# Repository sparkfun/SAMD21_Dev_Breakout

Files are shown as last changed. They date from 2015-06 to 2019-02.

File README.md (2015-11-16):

SparkFun SAMD21 Dev Breakout
========================================

SparkFun SAMD21 Dev Breakout

[*SparkFun SAMD21 Dev Breakout (DEV-13672)*](https://www.sparkfun.com/products/13672)

The SAMD21 Dev Breakout is an Arduino-sized breakout for the Atmel [ATSAMD21G18](http://www.atmel.com/devices/ATSAMD21G18A.aspx), a 32-bit ARM Cortex-M0+ processor with 256KB flash, 32KB SRAM, and an operating speed of up to 48MHz. The SAMD21 is compatible with the Arduino IDE, and libraries for the Arduino Zero.

Repository Contents
-------------------

* **/Documentation** - Data sheets, additional product information
* **/Firmware** - SAM_BA SAMD21 Bootloader
* **/Hardware** - Eagle design files (.brd, .sch)
* **/Production** - Production panel files (.brd)

Documentation
--------------
* **[Hookup Guide](https://learn.sparkfun.com/tutorials/samd21-Devdev-breakout-hookup-guide/resources--going-further)** - Basic hookup guide for the SAMD21 Dev Breakout.

Product Versions
----------------
* [DEV-13672](https://www.sparkfun.com/products/13672) - Initial product release - v10.
* [DEV-13672](https://www.sparkfun.com/products/13664) - The SparkFun SAMD21 _Mini_ Breakout -- a similar, Arduino-shaped version of this board.

Version History
---------------
* [v1.0](https://github.com/sparkfun/SAMD21_Dev_Breakout/tree/v10) - Initial release 

License Information
-------------------

This product is _**open source**_! 

Please review the LICENSE.md file for license information. 

If you have any questions or concerns on licensing, please contact techsupport@sparkfun.com.

Distributed as-is; no warranty is given.

- Your friends at SparkFun.

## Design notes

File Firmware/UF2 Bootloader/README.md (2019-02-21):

UF2 Bootloader for the SAMD21 DEV Breakout
==========================================
**Current Version**: UF2 Bootloader v3.2.2-1-gdec2fb7-dirty SFHWRO
**Updated**: 2/21/2019

What is UF2? It's probably best to read the documents [HERE](https://makecode.com/blog/one-chip-to-flash-them-all). The TLDR however, is that it's a bootloader that turns your micro-controller 
into a flash drive. The example bootloader provided here was created 2/21/2019
and further support is not guaranteed. However you can learn a bit about _how_
to build your own bootloader at Microsoft's [repo](https://github.com/Microsoft/uf2).
The hardest part will be ensuring that you have all the necessary build dependencies.

To update your SAMD21 DEV with the bootloader is simple. If you already have a
bootloader on it, i.e. you can see it populate in Arduino and/or Device
Manager, then all you have to do is open the "Update-Bootloader.ino" sketch and
upload it. Afterwards, you should see the SAMD21 pop up as a **SPARKFUN** drive. 
I have also included an "update" binary file for those that want to use some
GUI or command line interface instead, as well as _just_ the bootloader for
those that don't already have a bootloader installed on their micro-controller.

Circuit Python 
------------------
**Current Version**: 4.0.0-beta.1-46-g3d0757102   
**Updated**: 2/21/2019

Circuit Python is Adafruit's version of Micro Python. You can read general
information about it [HERE](https://learn.adafruit.com/welcome-to-circuitpython).
They also have some documentation on how to build a version of Circuit Python
on their website [here](https://learn.adafruit.com/building-circuitpython/build-circuitpython). 
I have included a build of it under the Circuit Python folder. Assuming that
you have uploaded the UF2 bootloader above, than all you need to do is drag and
drop the UF2 file in the Circuit Python folder into your **SPARKFUN** drive and 
you're good to go! The Sparkfun drive will momentarily disappear and a **CIRCUITPY** 
drive will take its place.

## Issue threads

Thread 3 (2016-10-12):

Unable to flash bootloader from Arduino IDE

dlabun, 2016-10-12:
With v1.2.1 of the SAMD21 core you cannot flash the bootloader from the Arduino IDE. The IDE is looking for the BIN file with the name "samd21_sam_ba.bin" when the file is actually named "samd21_sam_ba_sparkfun.bin"

ToniCorinne, 2017-02-07:
@jimblom can you see if this is still an issue? Thanks!

jimblom, 2017-02-08:
Shoot, looks like I forgot to close this issue out earlier.

"Burn bootloader" for SAMD21 Dev and Mini boards was fixed in the SparkFun SAMD core version 1.3.0. Verified that it works on the current version - 1.3.2.

Closed 2017-02-08.

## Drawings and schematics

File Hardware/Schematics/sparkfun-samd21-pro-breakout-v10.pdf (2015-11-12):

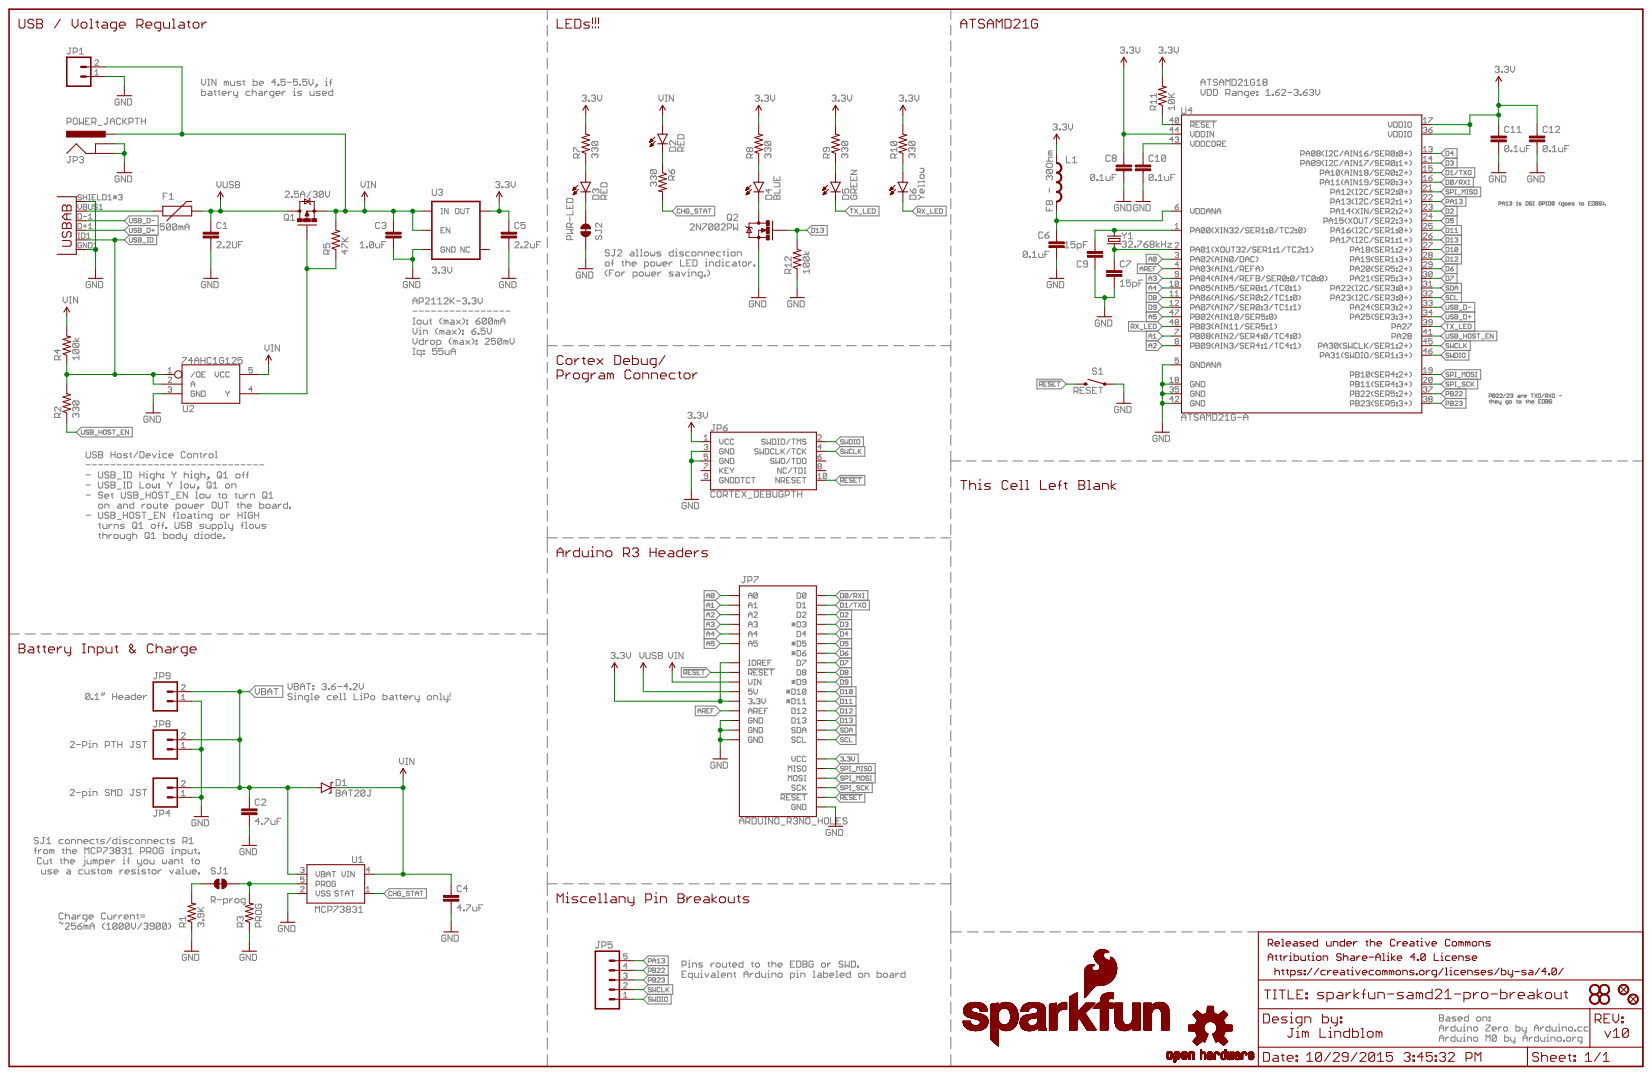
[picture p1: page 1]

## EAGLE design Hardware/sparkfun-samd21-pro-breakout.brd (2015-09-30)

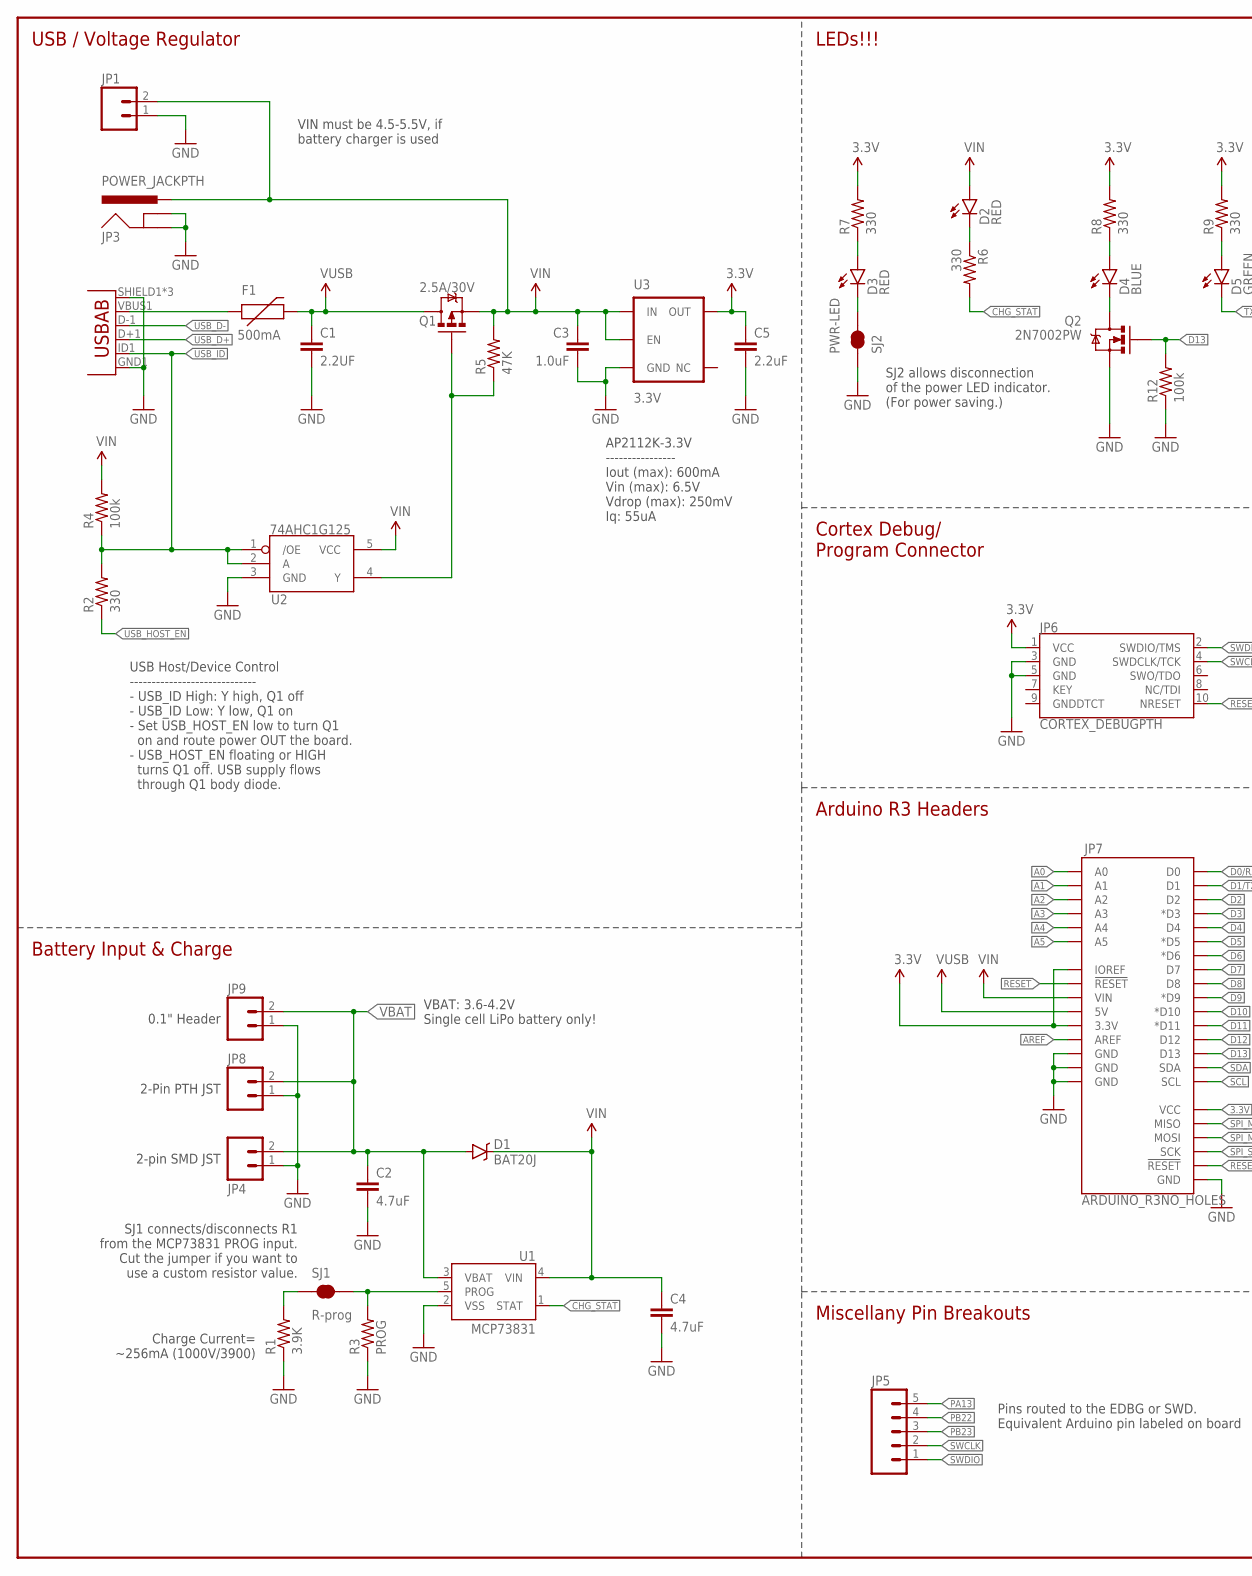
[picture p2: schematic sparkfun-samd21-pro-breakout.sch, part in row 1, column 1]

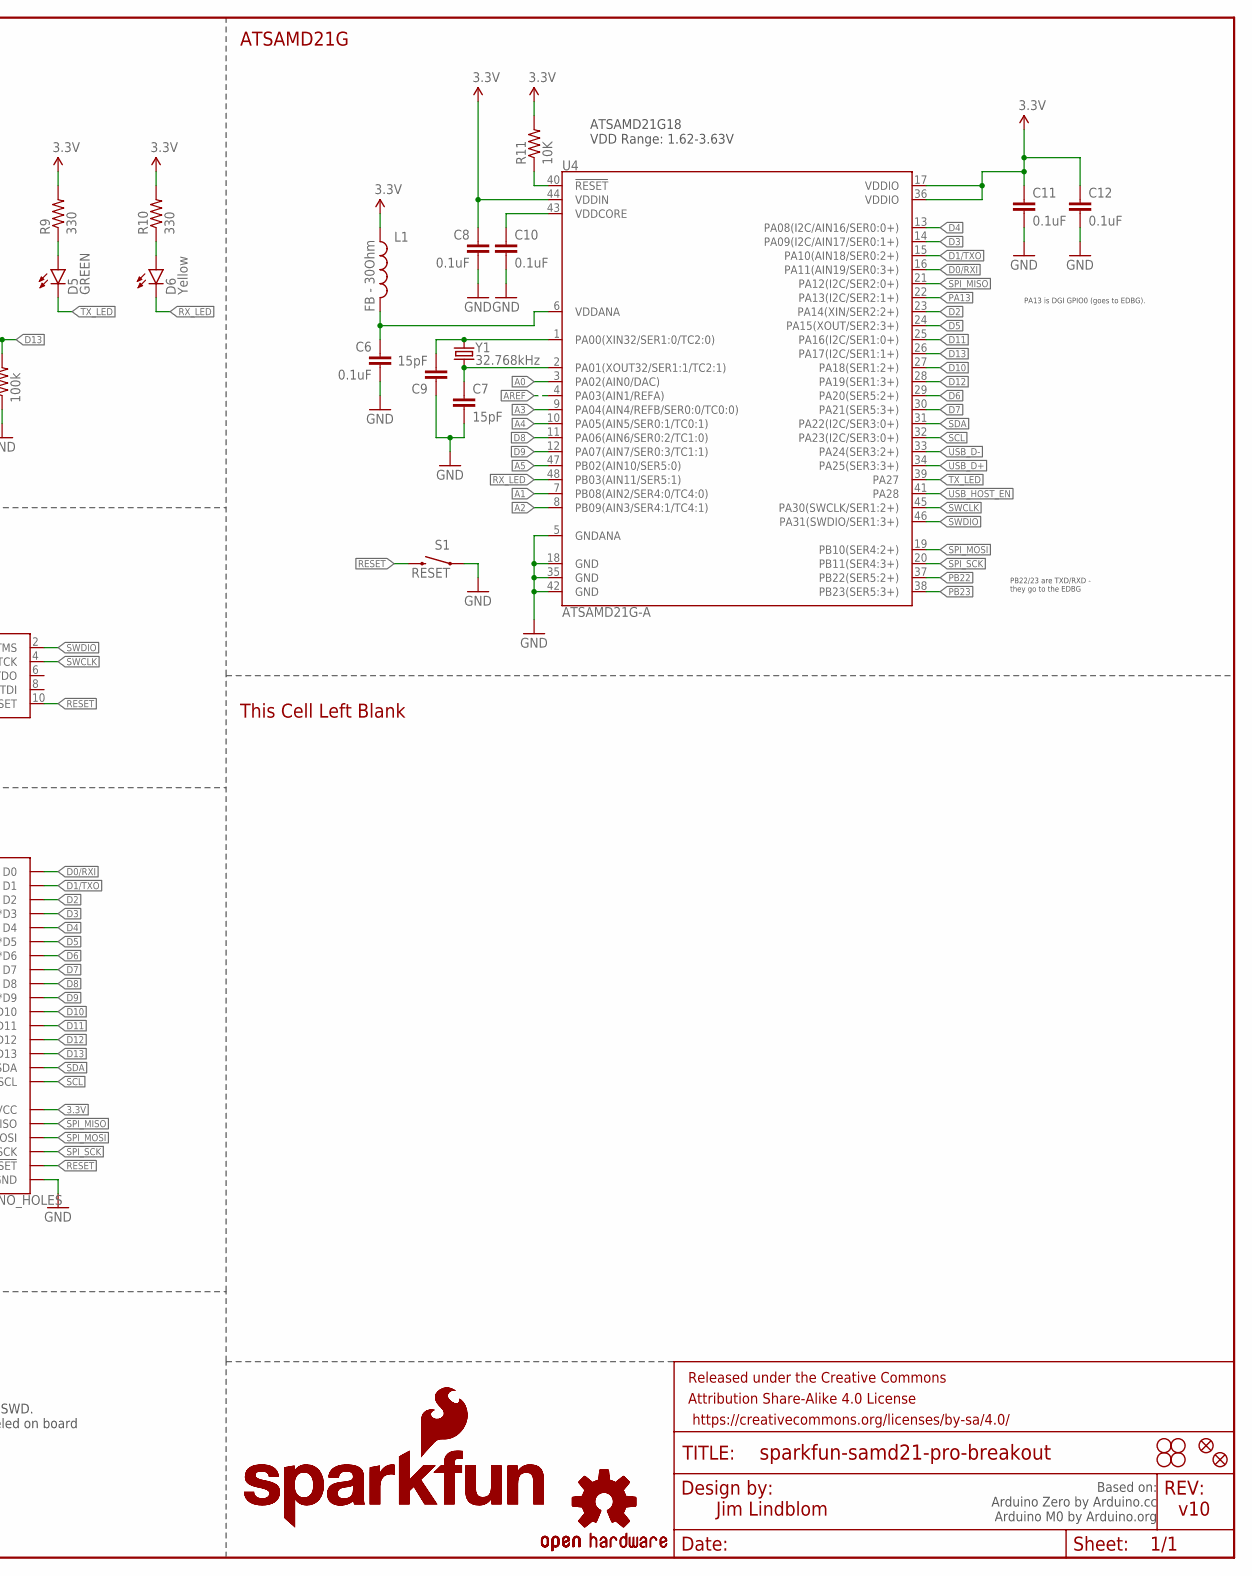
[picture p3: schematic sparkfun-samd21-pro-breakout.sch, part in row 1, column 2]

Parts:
C1: 2.2UF; 1206
C2, C4: 4.7uF; 0603-CAP
C3: 1.0uF; 0805-CAP
C5: 2.2uF; 0603-CAP
C6, C8, C10, C11, C12: 0.1uF; 0603-CAP
C7, C9: 15pF; 0603-CAP
D1: BAT20J; SOD-323
D2, D3: RED; LED-0603
D4: BLUE; LED-0603
D5: GREEN; LED-0603
D6: Yellow; LED-0603
F1: 500mA; PTC-1206
FID1, FID2: FIDUCIAL1X2; FIDUCIAL-1X2
FRAME1: FRAME-LEDGER; CREATIVE_COMMONS
JP1: M02PTH; 1X02
JP2: USB-ABCONN-11794; USB-AB-MICRO-SMD_V03
JP3: POWER_JACKPTH; POWER_JACK_PTH
JP4: M02-JST-2MM-SMT; JST-2-SMD
JP5: M05NO_SILK; 1X05_NO_SILK
JP6: CORTEX_DEBUGPTH; 2X5-PTH-1.27MM
JP7: ARDUINO_R3NO_HOLES; ARDUINO_R3_NO_HOLES
JP8: M02-JST-2-PTH-NO_SILK; JST-2-PTH-NS
JP9: M021X02_NO_SILK; 1X02_NO_SILK
L1: FB - 30Ohm; 0603
LOGO1: SFE_LOGO_NAME_FLAME.2_INCH; SFE_LOGO_NAME_FLAME_.2
LOGO2: SFE_LOGO_NAME_FLAME.4_INCH; SFE_LOGO_NAME_FLAME_.4
LOGO3: OSHW-LOGOS; OSHW-LOGO-S
LOGO4: OSHW-LOGOL; OSHW-LOGO-L
Q1: 2.5A/30V; SOT23-3
Q2: 2N7002PW; SOT323
R1: 3.9K; 0603
R2, R6, R7, R8, R9, R10: 330; 0603-RES
R3: PROG; 1/6W-RES
R4, R12: 100k; 0603-RES
R5: 47K; 0603-RES
R11: 10K; 0603-RES
S1: RESET; TACTILE-SWITCH-SMD
SJ1: R-prog; PAD-JUMPER-2-NC_BY_TRACE_YES_SILK
SJ2: PWR-LED; PAD-JUMPER-2-NC_BY_TRACE_NO_SILK
STANDOFF1, STANDOFF2, STANDOFF3, STANDOFF4: STAND-OFF
U1: MCP73831; SOT23-5
U2: 74AHC1G125; SOT23-5
U3: 3.3V; SOT23-5
U4: ATSAMD21G-A; TQFP-48
Y1: 32.768kHz; CRYSTAL-SMD-3.2X1.5MM

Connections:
3.3V: C5.1, C8.1, C11.1, C12.1, JP6.1 (VCC), JP7.3.3V, JP7.IOREF, JP7.VCC, L1.1, R7.2, R8.2, R9.2, R10.2, R11.2, U3.5 (OUT), U4.17 (VDDIO), U4.36 (VDDIO), U4.44 (VDDIN)
!RESET: JP6.10 (NRESET), JP7.RESET@1 (!RESET!), JP7.RESET@2 (!RESET!), R11.1, S1.3 (2), U4.40 (!RESET!)
A0: JP7.A0, U4.3 (PA02(AIN0/DAC))
A1: JP7.A1, U4.7 (PB08(AIN2/SER4:0/TC4:0))
A2: JP7.A2, U4.8 (PB09(AIN3/SER4:1/TC4:1))
A3: JP7.A3, U4.9 (PA04(AIN4/REFB/SER0:0/TC0:0))
A4: JP7.A4, U4.10 (PA05(AIN5/SER0:1/TC0:1))
A5: JP7.A5, U4.47 (PB02(AIN10/SER5:0))
AREF: JP7.AREF, U4.4 (PA03(AIN1/REFA))
CHG_STAT: R6.2, U1.1 (STAT)
D0/RXI: JP7.D0, U4.16 (PA11(AIN19/SER0:3+))
D1/TXO: JP7.D1, U4.15 (PA10(AIN18/SER0:2+))
D2: JP7.D2, U4.23 (PA14(XIN/SER2:2+))
D3: JP7.D3 (*D3), U4.14 (PA09(I2C/AIN17/SER0:1+))
D4: JP7.D4, U4.13 (PA08(I2C/AIN16/SER0:0+))
D5: JP7.D5 (*D5), U4.24 (PA15(XOUT/SER2:3+))
D6: JP7.D6 (*D6), U4.29 (PA20(SER5:2+))
D7: JP7.D7, U4.30 (PA21(SER5:3+))
D8: JP7.D8, U4.11 (PA06(AIN6/SER0:2/TC1:0))
D9: JP7.D9 (*D9), U4.12 (PA07(AIN7/SER0:3/TC1:1))
D10: JP7.D10 (*D10), U4.27 (PA18(SER1:2+))
D11: JP7.D11 (*D11), U4.25 (PA16(I2C/SER1:0+))
D12: JP7.D12, U4.28 (PA19(SER1:3+))
D13: JP7.D13, Q2.1 (G), R12.2, U4.26 (PA17(I2C/SER1:1+))
GND: C1.2, C2.2, C3.2, C4.2, C5.2, C6.2, C7.2, C8.2, C9.1, C10.2, C11.2, C12.2, JP1.1, JP2.GND1 (GND), JP2.SHIELD1 (SHIELD), JP2.SHIELD2 (SHIELD), JP2.SHIELD3 (SHIELD), JP3.GND, JP3.GNDBREAK, JP4.1 (2), JP6.3 (GND), JP6.5 (GND), JP7.GND@1 (GND), JP7.GND@2 (GND), JP7.GND@3 (GND), JP7.GND@4 (GND), JP8.1, JP9.1, Q2.2 (S), R1.1, R3.1, R12.1, S1.1, SJ2.1, U1.2 (VSS), U2.3 (GND), U3.2 (GND), U4.5 (GNDANA), U4.18 (GND), U4.35 (GND), U4.42 (GND)
unnamed: F1.1, JP2.VBUS1 (VBUS)
unnamed: C9.2, U4.1 (PA00(XIN32/SER1:0/TC2:0)), Y1.P$2 (2)
unnamed: D4.C, Q2.3 (D)
unnamed: C7.1, U4.2 (PA01(XOUT32/SER1:1/TC2:1)), Y1.P$1 (1)
unnamed: D3.A, R7.1
unnamed: D4.A, R8.1
unnamed: D2.C, R6.1
unnamed: D5.A, R9.1
unnamed: D6.A, R10.1
unnamed: D3.C, SJ2.2
unnamed: R1.2, SJ1.1
unnamed: R3.2, SJ1.2, U1.5 (PROG)
PA13: JP5.5, U4.22 (PA13(I2C/SER2:1+))
PB22: JP5.4, U4.37 (PB22(SER5:2+))
PB23: JP5.3, U4.38 (PB23(SER5:3+))
RX_LED: D6.C, U4.48 (PB03(AIN11/SER5:1))
SCL: JP7.SCL, U4.32 (PA23(I2C/SER3:0+))
SDA: JP7.SDA, U4.31 (PA22(I2C/SER3:0+))
SPI_MISO: JP7.MISO, U4.21 (PA12(I2C/SER2:0+))
SPI_MOSI: JP7.MOSI, U4.19 (PB10(SER4:2+))
SPI_SCK: JP7.SCK, U4.20 (PB11(SER4:3+))
SWCLK: JP5.2, JP6.4 (SWDCLK/TCK), U4.45 (PA30(SWCLK/SER1:2+))
SWDIO: JP5.1, JP6.2 (SWDIO/TMS), U4.46 (PA31(SWDIO/SER1:3+))
TX_LED: D5.C, U4.39 (PA27)
USB_D+: JP2.D+1 (D+), U4.34 (PA25(SER3:3+))
USB_D-: JP2.D-1 (D-), U4.33 (PA24(SER3:2+))
USB_HOST_EN: R2.1, U4.41 (PA28)
USB_HOST_POWER_EN: Q1.1 (G), R5.1, U2.4 (Y)
USB_ID: JP2.ID1 (USBID), R2.2, R4.1, U2.1 (/OE), U2.2 (A)
VBAT: C2.1, D1.A, JP4.2 (1), JP8.2, JP9.2, U1.3 (VBAT)
VDDANA: C6.1, L1.2, U4.6 (VDDANA)
VDDCORE: C10.1, U4.43 (VDDCORE)
VIN: C3.1, C4.1, D1.C, D2.A, JP1.2, JP3.PWR, JP7.VIN, Q1.2 (S), R4.2, R5.2, U1.4 (VIN), U2.5 (VCC), U3.1 (IN), U3.3 (EN)
VUSB: C1.1, F1.2, JP7.5V, Q1.3 (D)

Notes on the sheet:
PB22/23 are TXD/RXD - they go to the EDBG
PA13 is DGI GPIO0 (goes to EDBG).
USB / Voltage Regulator
LEDs!!!
Cortex Debug/ Program Connector
Arduino R3 Headers
ATSAMD21G
Jim Lindblom
v10
Charge Current= ~256mA (1000V/3900)
SJ1 connects/disconnects R1 from the MCP73831 PROG input. Cut the jumper if you want to use a custom resistor value.
Battery Input & Charge
SJ2 allows disconnection of the power LED indicator. (For power saving.)
Miscellany Pin Breakouts
This Cell Left Blank
VIN must be 4.5-5.5V, if battery charger is used
ATSAMD21G18 VDD Range: 1.62-3.63V
Based on: Arduino Zero by Arduino.cc Arduino M0 by Arduino.org
0.1" Header
2-Pin PTH JST
2-pin SMD JST
AP2112K-3.3V ---------------- Iout (max): 600mA Vin (max): 6.5V Vdrop (max): 250mV Iq: 55uA
USB Host/Device Control ----------------------------- - USB_ID High: Y high, Q1 off - USB_ID Low: Y low, Q1 on - Set USB_HOST_EN low to turn Q1 on and route power OUT the board. - USB_HOST_EN floating or HIGH turns Q1 off. USB supply flows through Q1 body diode.
Pins routed to the EDBG or SWD. Equivalent Arduino pin labeled on board
VBAT: 3.6-4.2V Single cell LiPo battery only\!

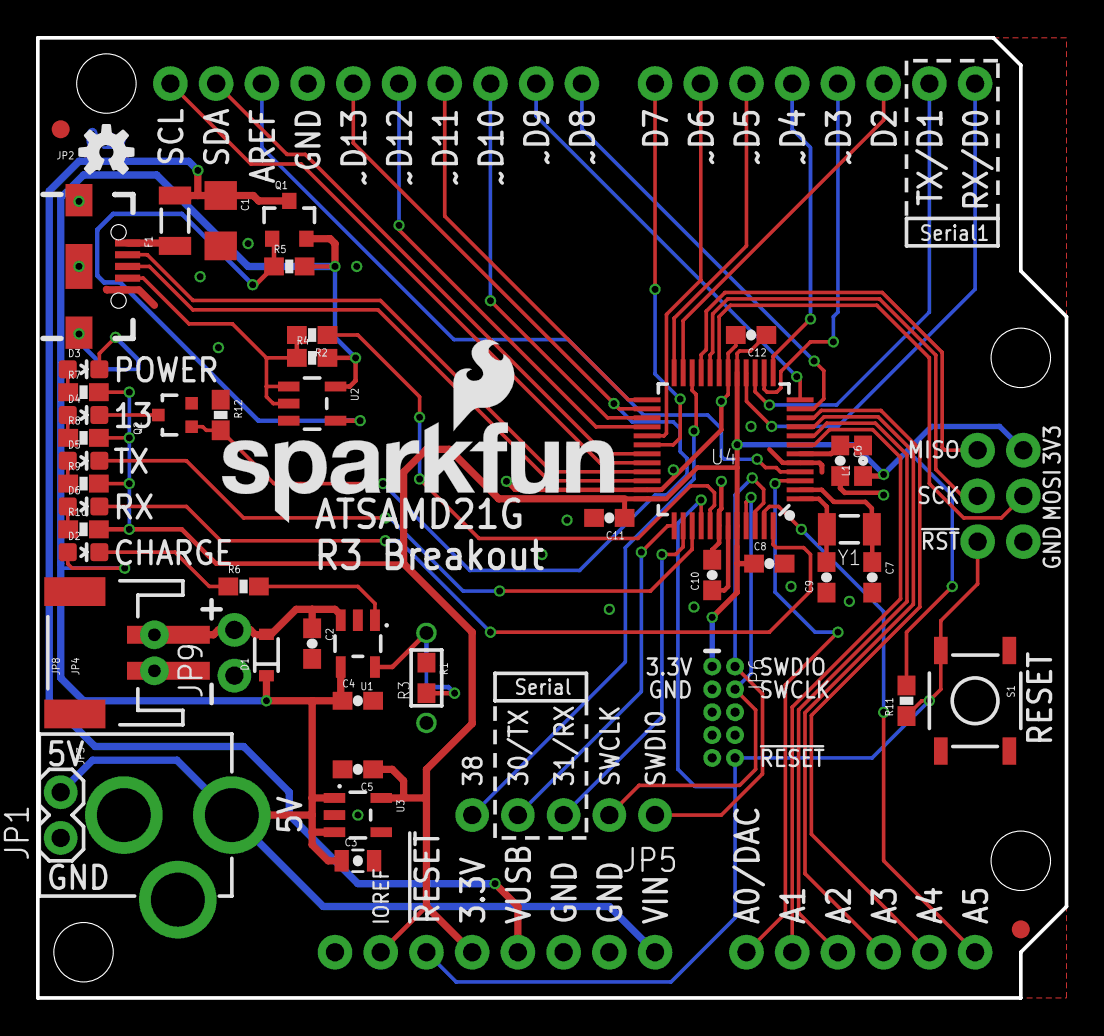
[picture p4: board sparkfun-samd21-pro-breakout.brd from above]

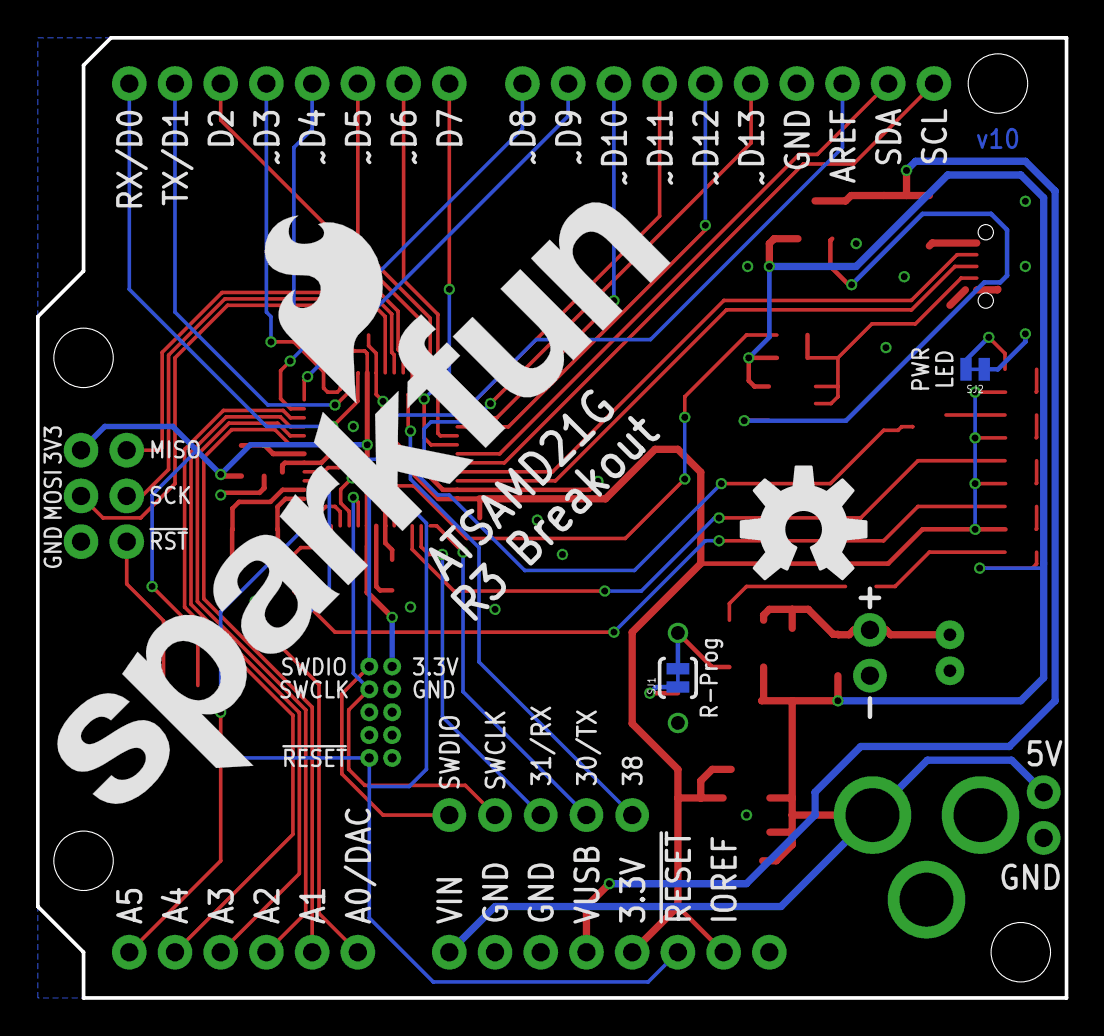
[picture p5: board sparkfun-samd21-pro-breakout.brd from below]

Board: 2 copper layers, 57.1 x 53.3 mm, 62 parts (4 on the bottom side), 59 nets.

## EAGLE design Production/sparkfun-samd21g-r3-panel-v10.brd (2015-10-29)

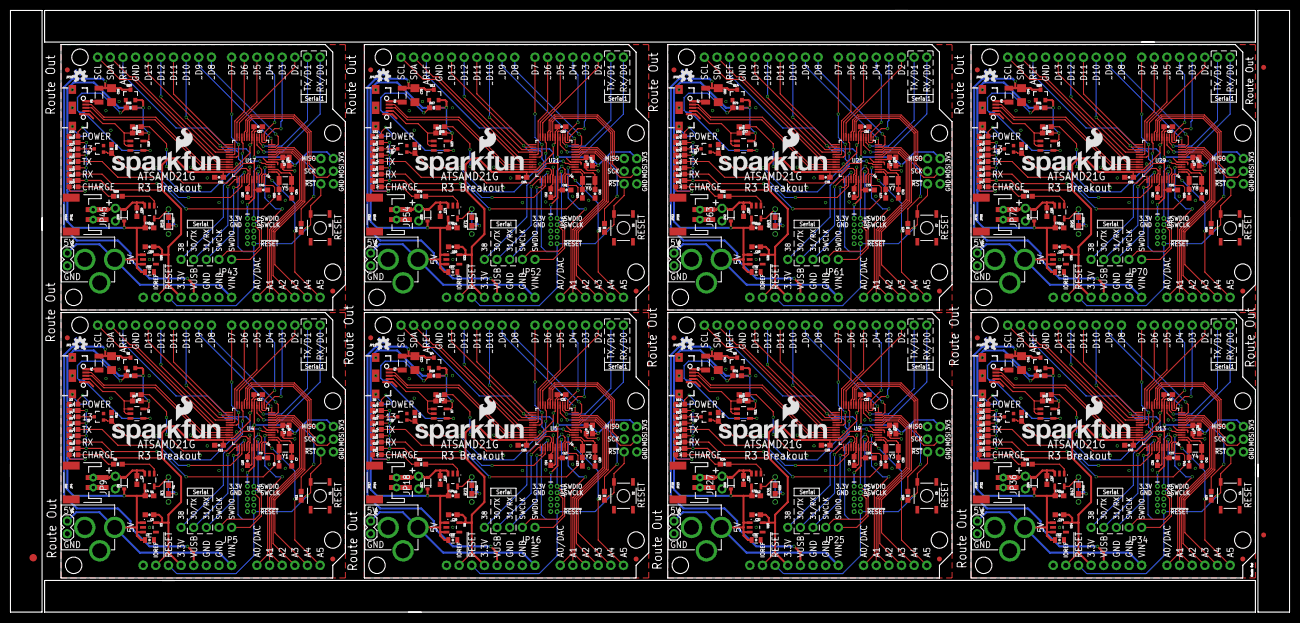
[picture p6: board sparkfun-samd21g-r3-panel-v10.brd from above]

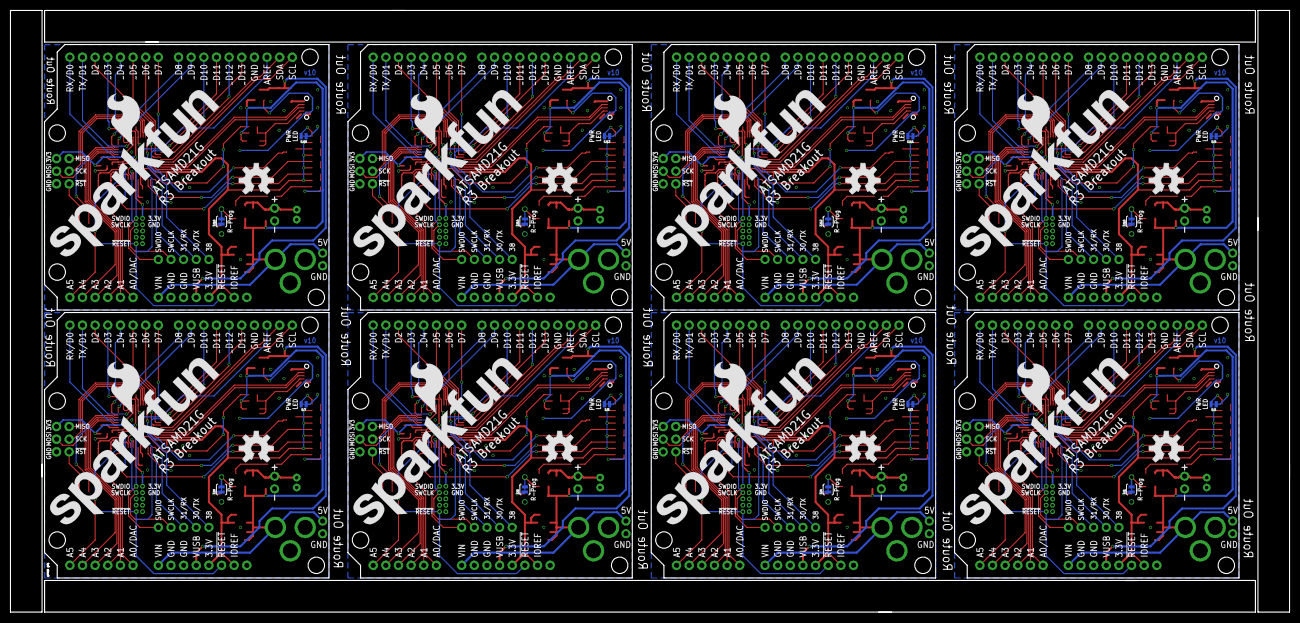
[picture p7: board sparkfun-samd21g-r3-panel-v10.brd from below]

Board: 2 copper layers, 257.0 x 120.9 mm, 491 parts (32 on the bottom side), 472 nets.

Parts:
C1, C22, C34, C46, C58, C70, C82, C94: 2.2UF; 1206
C2, C4, C23, C24, C35, C36, C47, C48, C59, C60, C71, C72, C83, C84, C95, C96: 4.7uF; 0603-CAP
C3, C19, C31, C43, C55, C67, C79, C91: 1.0uF; 0805-CAP
C5, C20, C32, C44, C56, C68, C80, C92: 2.2uF; 0603-CAP
C6, C8, C10, C11, C12, C13, C14, C15, C16, C21, C25, C26, C27, C28, C33, C37, C38, C39, C40, C45, C49, C50, C51, C52, C57, C61, C62, C63, C64, C69, C73, C74, C75, C76, C81, C85, C86, C87, C88, C93: 0.1uF; 0603-CAP
C7, C9, C17, C18, C29, C30, C41, C42, C53, C54, C65, C66, C77, C78, C89, C90: 15pF; 0603-CAP
D1, D12, D18, D24, D30, D36, D42, D48: BAT20J; SOD-323
D2, D3, D8, D11, D14, D17, D20, D23, D26, D29, D32, D35, D38, D41, D44, D47: RED; LED-0603
D4, D9, D15, D21, D27, D33, D39, D45: BLUE; LED-0603
D5, D7, D13, D19, D25, D31, D37, D43: GREEN; LED-0603
D6, D10, D16, D22, D28, D34, D40, D46: Yellow; LED-0603
E$1: FIDUCIAL-1.5X3
E$5, E$6: FIDUCIAL-1X2
F1, F2, F3, F4, F5, F6, F7, F8: 500mA; PTC-1206
FID1, FID2, FID3, FID4, FID5, FID6, FID7, FID8, FID9, FID10, FID11, FID12, FID13, FID14, FID15, FID16: FIDUCIAL1X2; FIDUCIAL-1X2
JP1, JP15, JP24, JP33, JP42, JP51, JP60, JP69: 1X02
JP2, JP11, JP20, JP29, JP38, JP47, JP56, JP65: USB-AB-MICRO-SMD_V03
JP3, JP13, JP22, JP31, JP40, JP49, JP58, JP67: POWER_JACKPTH; POWER_JACK_PTH
JP4, JP14, JP23, JP32, JP41, JP50, JP59, JP68: JST-2-SMD
JP5, JP16, JP25, JP34, JP43, JP52, JP61, JP70: 1X05_NO_SILK
JP6, JP10, JP19, JP28, JP37, JP46, JP55, JP64: CORTEX_DEBUGPTH; 2X5-PTH-1.27MM
JP7, JP12, JP21, JP30, JP39, JP48, JP57, JP66: ARDUINO_R3NO_HOLES; ARDUINO_R3_NO_HOLES
JP8, JP17, JP26, JP35, JP44, JP53, JP62, JP71: JST-2-PTH-NS
JP9, JP18, JP27, JP36, JP45, JP54, JP63, JP72: 1X02_NO_SILK
L1, L2, L3, L4, L5, L6, L7, L8: FB - 30Ohm; 0603
LOGO1, LOGO6, LOGO10, LOGO14, LOGO18, LOGO22, LOGO26, LOGO30: SFE_LOGO_NAME_FLAME.2_INCH; SFE_LOGO_NAME_FLAME_.2
LOGO2, LOGO7, LOGO11, LOGO15, LOGO19, LOGO23, LOGO27, LOGO31: SFE_LOGO_NAME_FLAME.4_INCH; SFE_LOGO_NAME_FLAME_.4
LOGO3, LOGO5, LOGO9, LOGO13, LOGO17, LOGO21, LOGO25, LOGO29: OSHW-LOGOS; OSHW-LOGO-S
LOGO4, LOGO8, LOGO12, LOGO16, LOGO20, LOGO24, LOGO28, LOGO32: OSHW-LOGOL; OSHW-LOGO-L
Q1, Q4, Q6, Q8, Q10, Q12, Q14, Q16: 2.5A/30V; SOT23-3
Q2, Q3, Q5, Q7, Q9, Q11, Q13, Q15: 2N7002PW; SOT323
R1, R21, R33, R45, R57, R69, R81, R93: 3.9K; 0603
R2, R6, R7, R8, R9, R10, R14, R15, R17, R18, R20, R22, R26, R27, R29, R30, R32, R34, R38, R39, R41, R42, R44, R46, R50, R51, R53, R54, R56, R58, R62, R63, R65, R66, R68, R70, R74, R75, R77, R78, R80, R82, R86, R87, R89, R90, R92, R94: 330; 0603-RES
R3, R23, R35, R47, R59, R71, R83, R95: PROG; 1/6W-RES
R4, R12, R16, R24, R28, R36, R40, R48, R52, R60, R64, R72, R76, R84, R88, R96: 100k; 0603-RES
R5, R19, R31, R43, R55, R67, R79, R91: 47K; 0603-RES
R11, R13, R25, R37, R49, R61, R73, R85: 10K; 0603-RES
S1, S2, S3, S4, S5, S6, S7, S8: RESET; TACTILE-SWITCH-SMD
SJ1, SJ4, SJ6, SJ8, SJ10, SJ12, SJ14, SJ16: R-prog; PAD-JUMPER-2-NC_BY_TRACE_YES_SILK
SJ2, SJ3, SJ5, SJ7, SJ9, SJ11, SJ13, SJ15: PWR-LED; PAD-JUMPER-2-NC_BY_TRACE_NO_SILK
STANDOFF1, STANDOFF2, STANDOFF3, STANDOFF4, STANDOFF5, STANDOFF6, STANDOFF7, STANDOFF8, STANDOFF9, STANDOFF10, STANDOFF11, STANDOFF12, STANDOFF13, STANDOFF14, STANDOFF15, STANDOFF16, STANDOFF17, STANDOFF18, STANDOFF19, STANDOFF20, STANDOFF21, STANDOFF22, STANDOFF23, STANDOFF24, STANDOFF25, STANDOFF26, STANDOFF27, STANDOFF28, STANDOFF29, STANDOFF30, STANDOFF31, STANDOFF32: STAND-OFF
U1, U8, U12, U16, U20, U24, U28, U32: MCP73831; SOT23-5
U2, U7, U11, U15, U19, U23, U27, U31: 74AHC1G125; SOT23-5
U3, U6, U10, U14, U18, U22, U26, U30: 3.3V; SOT23-5
U4, U5, U9, U13, U17, U21, U25, U29: ATSAMD21G-A; TQFP-48
Y1, Y2, Y3, Y4, Y5, Y6, Y7, Y8: 32.768kHz; CRYSTAL-SMD-3.2X1.5MM

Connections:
3.3V: C5.1, C8.1, C11.1, C12.1, JP6.1, JP7.3.3V, JP7.IOREF, JP7.VCC, L1.1, R7.2, R8.2, R9.2, R10.2, R11.2, U3.5, U4.17, U4.36, U4.44
3.3V1: C13.1, C16.1, C20.1, C21.1, JP10.1, JP12.3.3V, JP12.IOREF, JP12.VCC, L2.1, R13.2, R14.2, R15.2, R18.2, R20.2, U5.17, U5.36, U5.44, U6.5
3.3V2: C25.1, C28.1, C32.1, C33.1, JP19.1, JP21.3.3V, JP21.IOREF, JP21.VCC, L3.1, R25.2, R26.2, R27.2, R30.2, R32.2, U9.17, U9.36, U9.44, U10.5
3.3V3: C37.1, C40.1, C44.1, C45.1, JP28.1, JP30.3.3V, JP30.IOREF, JP30.VCC, L4.1, R37.2, R38.2, R39.2, R42.2, R44.2, U13.17, U13.36, U13.44, U14.5
3.3V4: C49.1, C52.1, C56.1, C57.1, JP37.1, JP39.3.3V, JP39.IOREF, JP39.VCC, L5.1, R49.2, R50.2, R51.2, R54.2, R56.2, U17.17, U17.36, U17.44, U18.5
3.3V5: C61.1, C64.1, C68.1, C69.1, JP46.1, JP48.3.3V, JP48.IOREF, JP48.VCC, L6.1, R61.2, R62.2, R63.2, R66.2, R68.2, U21.17, U21.36, U21.44, U22.5
3.3V6: C73.1, C76.1, C80.1, C81.1, JP55.1, JP57.3.3V, JP57.IOREF, JP57.VCC, L7.1, R73.2, R74.2, R75.2, R78.2, R80.2, U25.17, U25.36, U25.44, U26.5
3.3V7: C85.1, C88.1, C92.1, C93.1, JP64.1, JP66.3.3V, JP66.IOREF, JP66.VCC, L8.1, R85.2, R86.2, R87.2, R90.2, R92.2, U29.17, U29.36, U29.44, U30.5
!RESET: JP6.10, JP7.RESET@1, JP7.RESET@2, R11.1, S1.3, U4.40
!RESET1: JP10.10, JP12.RESET@1, JP12.RESET@2, R13.1, S2.3, U5.40
!RESET2: JP19.10, JP21.RESET@1, JP21.RESET@2, R25.1, S3.3, U9.40
!RESET3: JP28.10, JP30.RESET@1, JP30.RESET@2, R37.1, S4.3, U13.40
!RESET4: JP37.10, JP39.RESET@1, JP39.RESET@2, R49.1, S5.3, U17.40
!RESET5: JP46.10, JP48.RESET@1, JP48.RESET@2, R61.1, S6.3, U21.40
!RESET6: JP55.10, JP57.RESET@1, JP57.RESET@2, R73.1, S7.3, U25.40
!RESET7: JP64.10, JP66.RESET@1, JP66.RESET@2, R85.1, S8.3, U29.40
A0: JP7.A0, U4.3
A1: JP7.A1, U4.7
A2: JP7.A2, U4.8
A3: JP7.A3, U4.9
A4: JP7.A4, U4.10
A5: JP7.A5, U4.47
A6: JP12.A3, U5.9
A7: JP12.A2, U5.8
A8: JP12.A1, U5.7
A9: JP12.A0, U5.3
A10: JP12.A4, U5.10
A11: JP12.A5, U5.47
A12: JP21.A3, U9.9
A13: JP21.A2, U9.8
A14: JP21.A1, U9.7
A15: JP21.A0, U9.3
A16: JP21.A4, U9.10
A17: JP21.A5, U9.47
A18: JP30.A3, U13.9
A19: JP30.A2, U13.8
A20: JP30.A1, U13.7
A21: JP30.A0, U13.3
A22: JP30.A4, U13.10
A23: JP30.A5, U13.47
A24: JP39.A3, U17.9
A25: JP39.A2, U17.8
A26: JP39.A1, U17.7
A27: JP39.A0, U17.3
A28: JP39.A4, U17.10
A29: JP39.A5, U17.47
A30: JP48.A3, U21.9
A31: JP48.A2, U21.8
A32: JP48.A1, U21.7
A33: JP48.A0, U21.3
A34: JP48.A4, U21.10
A35: JP48.A5, U21.47
A36: JP57.A3, U25.9
A37: JP57.A2, U25.8
A38: JP57.A1, U25.7
A39: JP57.A0, U25.3
A40: JP57.A4, U25.10
A41: JP57.A5, U25.47
A42: JP66.A3, U29.9
A43: JP66.A2, U29.8
A44: JP66.A1, U29.7
A45: JP66.A0, U29.3
A46: JP66.A4, U29.10
A47: JP66.A5, U29.47
AREF: JP7.AREF, U4.4
AREF1: JP12.AREF, U5.4
AREF2: JP21.AREF, U9.4
AREF3: JP30.AREF, U13.4
AREF4: JP39.AREF, U17.4
AREF5: JP48.AREF, U21.4
AREF6: JP57.AREF, U25.4
AREF7: JP66.AREF, U29.4
CHG_STAT: R6.2, U1.1
CHG_STAT1: R22.2, U8.1
CHG_STAT2: R34.2, U12.1
CHG_STAT3: R46.2, U16.1
CHG_STAT4: R58.2, U20.1
CHG_STAT5: R70.2, U24.1
CHG_STAT6: R82.2, U28.1
CHG_STAT7: R94.2, U32.1
D0/RXI: JP7.D0, U4.16
D0/RXI1: JP12.D0, U5.16
D0/RXI2: JP21.D0, U9.16
D0/RXI3: JP30.D0, U13.16
D0/RXI4: JP39.D0, U17.16
D0/RXI5: JP48.D0, U21.16
D0/RXI6: JP57.D0, U25.16
D0/RXI7: JP66.D0, U29.16
D1: JP12.D4, U5.13
D1/TXO: JP7.D1, U4.15
D1/TXO1: JP12.D1, U5.15
D1/TXO2: JP21.D1, U9.15
D1/TXO3: JP30.D1, U13.15
D1/TXO4: JP39.D1, U17.15
D1/TXO5: JP48.D1, U21.15
D1/TXO6: JP57.D1, U25.15
D1/TXO7: JP66.D1, U29.15
D2: JP7.D2, U4.23
D3: JP7.D3, U4.14
D4: JP7.D4, U4.13
D5: JP7.D5, U4.24
D6: JP7.D6, U4.29
D7: JP7.D7, U4.30
D8: JP7.D8, U4.11
D9: JP7.D9, U4.12
D10: JP7.D10, U4.27
D11: JP7.D11, U4.25
D12: JP7.D12, U4.28
D13: JP7.D13, Q2.1, R12.2, U4.26
D14: JP12.D3, U5.14
D15: JP12.D2, U5.23
D16: JP12.D5, U5.24
D17: JP12.D6, U5.29
D18: JP12.D7, U5.30
D19: JP12.D8, U5.11
D20: JP12.D9, U5.12
D21: JP12.D12, U5.28
D22: JP12.D11, U5.25
D23: JP12.D10, U5.27
D24: JP12.D13, Q3.1, R24.2, U5.26
D25: JP21.D4, U9.13
D26: JP21.D3, U9.14
D27: JP21.D2, U9.23
D28: JP21.D5, U9.24
D29: JP21.D6, U9.29
D30: JP21.D7, U9.30
D31: JP21.D8, U9.11
D32: JP21.D9, U9.12
D33: JP21.D12, U9.28
D34: JP21.D11, U9.25
D35: JP21.D10, U9.27
D36: JP21.D13, Q5.1, R36.2, U9.26
D37: JP30.D4, U13.13
D38: JP30.D3, U13.14
D39: JP30.D2, U13.23
D40: JP30.D5, U13.24
D41: JP30.D6, U13.29
D42: JP30.D7, U13.30
D43: JP30.D8, U13.11
D44: JP30.D9, U13.12
D45: JP30.D12, U13.28
D46: JP30.D11, U13.25
D47: JP30.D10, U13.27
D48: JP30.D13, Q7.1, R48.2, U13.26
D49: JP39.D4, U17.13
D50: JP39.D3, U17.14
D51: JP39.D2, U17.23
D52: JP39.D5, U17.24
D53: JP39.D6, U17.29
D54: JP39.D7, U17.30
D55: JP39.D8, U17.11
D56: JP39.D9, U17.12
D57: JP39.D12, U17.28
D58: JP39.D11, U17.25
D59: JP39.D10, U17.27
D60: JP39.D13, Q9.1, R60.2, U17.26
D61: JP48.D4, U21.13
D62: JP48.D3, U21.14
D63: JP48.D2, U21.23
D64: JP48.D5, U21.24
D65: JP48.D6, U21.29
D66: JP48.D7, U21.30
D67: JP48.D8, U21.11
D68: JP48.D9, U21.12
D69: JP48.D12, U21.28
D70: JP48.D11, U21.25
D71: JP48.D10, U21.27
D72: JP48.D13, Q11.1, R72.2, U21.26
D73: JP57.D4, U25.13
D74: JP57.D3, U25.14
D75: JP57.D2, U25.23
D76: JP57.D5, U25.24
D77: JP57.D6, U25.29
D78: JP57.D7, U25.30
D79: JP57.D8, U25.11
D80: JP57.D9, U25.12
D81: JP57.D12, U25.28
D82: JP57.D11, U25.25
D83: JP57.D10, U25.27
D84: JP57.D13, Q13.1, R84.2, U25.26
D85: JP66.D4, U29.13
D86: JP66.D3, U29.14
D87: JP66.D2, U29.23
D88: JP66.D5, U29.24
D89: JP66.D6, U29.29
D90: JP66.D7, U29.30
D91: JP66.D8, U29.11
D92: JP66.D9, U29.12
D93: JP66.D12, U29.28
D94: JP66.D11, U29.25
D95: JP66.D10, U29.27
D96: JP66.D13, Q15.1, R96.2, U29.26
GND: C1.2, C2.2, C3.2, C4.2, C5.2, C6.2, C7.2, C8.2, C9.1, C10.2, C11.2, C12.2, JP1.1, JP2.GND1, JP2.SHIELD1, JP2.SHIELD2, JP2.SHIELD3, JP3.GND, JP3.GNDBREAK, JP4.1, JP6.3, JP6.5, JP7.GND@1, JP7.GND@2, JP7.GND@3, JP7.GND@4, JP8.1, JP9.1, Q2.2, R1.1, R3.1, R12.1, S1.1, SJ2.1, U1.2, U2.3, U3.2, U4.5, U4.18, U4.35, U4.42
GND1: C13.2, C14.2, C15.2, C16.2, C17.1, C18.2, C19.2, C20.2, C21.2, C22.2, C23.2, C24.2, JP10.3, JP10.5, JP11.GND1, JP11.SHIELD1, JP11.SHIELD2, JP11.SHIELD3, JP12.GND@1, JP12.GND@2, JP12.GND@3, JP12.GND@4, JP13.GND, JP13.GNDBREAK, JP14.1, JP15.1, JP17.1, JP18.1, Q3.2, R21.1, R23.1, R24.1, S2.1, SJ3.1, U5.5, U5.18, U5.35, U5.42, U6.2, U7.3, U8.2
GND2: C25.2, C26.2, C27.2, C28.2, C29.1, C30.2, C31.2, C32.2, C33.2, C34.2, C35.2, C36.2, JP19.3, JP19.5, JP20.GND1, JP20.SHIELD1, JP20.SHIELD2, JP20.SHIELD3, JP21.GND@1, JP21.GND@2, JP21.GND@3, JP21.GND@4, JP22.GND, JP22.GNDBREAK, JP23.1, JP24.1, JP26.1, JP27.1, Q5.2, R33.1, R35.1, R36.1, S3.1, SJ5.1, U9.5, U9.18, U9.35, U9.42, U10.2, U11.3, U12.2
GND3: C37.2, C38.2, C39.2, C40.2, C41.1, C42.2, C43.2, C44.2, C45.2, C46.2, C47.2, C48.2, JP28.3, JP28.5, JP29.GND1, JP29.SHIELD1, JP29.SHIELD2, JP29.SHIELD3, JP30.GND@1, JP30.GND@2, JP30.GND@3, JP30.GND@4, JP31.GND, JP31.GNDBREAK, JP32.1, JP33.1, JP35.1, JP36.1, Q7.2, R45.1, R47.1, R48.1, S4.1, SJ7.1, U13.5, U13.18, U13.35, U13.42, U14.2, U15.3, U16.2
GND4: C49.2, C50.2, C51.2, C52.2, C53.1, C54.2, C55.2, C56.2, C57.2, C58.2, C59.2, C60.2, JP37.3, JP37.5, JP38.GND1, JP38.SHIELD1, JP38.SHIELD2, JP38.SHIELD3, JP39.GND@1, JP39.GND@2, JP39.GND@3, JP39.GND@4, JP40.GND, JP40.GNDBREAK, JP41.1, JP42.1, JP44.1, JP45.1, Q9.2, R57.1, R59.1, R60.1, S5.1, SJ9.1, U17.5, U17.18, U17.35, U17.42, U18.2, U19.3, U20.2
GND5: C61.2, C62.2, C63.2, C64.2, C65.1, C66.2, C67.2, C68.2, C69.2, C70.2, C71.2, C72.2, JP46.3, JP46.5, JP47.GND1, JP47.SHIELD1, JP47.SHIELD2, JP47.SHIELD3, JP48.GND@1, JP48.GND@2, JP48.GND@3, JP48.GND@4, JP49.GND, JP49.GNDBREAK, JP50.1, JP51.1, JP53.1, JP54.1, Q11.2, R69.1, R71.1, R72.1, S6.1, SJ11.1, U21.5, U21.18, U21.35, U21.42, U22.2, U23.3, U24.2
GND6: C73.2, C74.2, C75.2, C76.2, C77.1, C78.2, C79.2, C80.2, C81.2, C82.2, C83.2, C84.2, JP55.3, JP55.5, JP56.GND1, JP56.SHIELD1, JP56.SHIELD2, JP56.SHIELD3, JP57.GND@1, JP57.GND@2, JP57.GND@3, JP57.GND@4, JP58.GND, JP58.GNDBREAK, JP59.1, JP60.1, JP62.1, JP63.1, Q13.2, R81.1, R83.1, R84.1, S7.1, SJ13.1, U25.5, U25.18, U25.35, U25.42, U26.2, U27.3, U28.2
GND7: C85.2, C86.2, C87.2, C88.2, C89.1, C90.2, C91.2, C92.2, C93.2, C94.2, C95.2, C96.2, JP64.3, JP64.5, JP65.GND1, JP65.SHIELD1, JP65.SHIELD2, JP65.SHIELD3, JP66.GND@1, JP66.GND@2, JP66.GND@3, JP66.GND@4, JP67.GND, JP67.GNDBREAK, JP68.1, JP69.1, JP71.1, JP72.1, Q15.2, R93.1, R95.1, R96.1, S8.1, SJ15.1, U29.5, U29.18, U29.35, U29.42, U30.2, U31.3, U32.2
unnamed: F1.1, JP2.VBUS1
unnamed: C9.2, U4.1, Y1.P$2
unnamed: D4.C, Q2.3
unnamed: C7.1, U4.2, Y1.P$1
unnamed: D3.A, R7.1
unnamed: D4.A, R8.1
unnamed: C17.2, U5.1, Y2.P$2
unnamed: D2.C, R6.1
unnamed: C18.1, U5.2, Y2.P$1
unnamed: D5.A, R9.1
unnamed: D6.A, R10.1
unnamed: D3.C, SJ2.2
unnamed: R1.2, SJ1.1
unnamed: D8.A, R14.1
unnamed: R3.2, SJ1.2, U1.5
unnamed: D9.A, R15.1
unnamed: D9.C, Q3.3
unnamed: F2.1, JP11.VBUS1
unnamed: D7.A, R18.1
unnamed: D10.A, R20.1
unnamed: D8.C, SJ3.2
unnamed: R21.2, SJ4.1
unnamed: R23.2, SJ4.2, U8.5
unnamed: D11.C, R22.1
unnamed: C29.2, U9.1, Y3.P$2
unnamed: C30.1, U9.2, Y3.P$1
unnamed: D14.A, R26.1
unnamed: D15.A, R27.1
unnamed: D15.C, Q5.3
unnamed: F3.1, JP20.VBUS1
unnamed: D13.A, R30.1
unnamed: D16.A, R32.1
unnamed: D14.C, SJ5.2
unnamed: R33.2, SJ6.1
unnamed: R35.2, SJ6.2, U12.5
unnamed: D17.C, R34.1
unnamed: C41.2, U13.1, Y4.P$2
unnamed: C42.1, U13.2, Y4.P$1
unnamed: D20.A, R38.1
unnamed: D21.A, R39.1
unnamed: D21.C, Q7.3
unnamed: F4.1, JP29.VBUS1
unnamed: D19.A, R42.1
unnamed: D22.A, R44.1
unnamed: D20.C, SJ7.2
unnamed: R45.2, SJ8.1
unnamed: R47.2, SJ8.2, U16.5
unnamed: D23.C, R46.1
unnamed: C53.2, U17.1, Y5.P$2
unnamed: C54.1, U17.2, Y5.P$1
unnamed: D26.A, R50.1
unnamed: D27.A, R51.1
unnamed: D27.C, Q9.3
unnamed: F5.1, JP38.VBUS1
unnamed: D25.A, R54.1
unnamed: D28.A, R56.1
unnamed: D26.C, SJ9.2
unnamed: R57.2, SJ10.1
unnamed: R59.2, SJ10.2, U20.5
unnamed: D29.C, R58.1
unnamed: C65.2, U21.1, Y6.P$2
unnamed: C66.1, U21.2, Y6.P$1
unnamed: D32.A, R62.1
unnamed: D33.A, R63.1
unnamed: D33.C, Q11.3
unnamed: F6.1, JP47.VBUS1
unnamed: D31.A, R66.1
unnamed: D34.A, R68.1
unnamed: D32.C, SJ11.2
unnamed: R69.2, SJ12.1
unnamed: R71.2, SJ12.2, U24.5
unnamed: D35.C, R70.1
unnamed: C77.2, U25.1, Y7.P$2
unnamed: C78.1, U25.2, Y7.P$1
unnamed: D38.A, R74.1
unnamed: D39.A, R75.1
unnamed: D39.C, Q13.3
unnamed: F7.1, JP56.VBUS1
unnamed: D37.A, R78.1
unnamed: D40.A, R80.1
unnamed: D38.C, SJ13.2
unnamed: R81.2, SJ14.1
unnamed: R83.2, SJ14.2, U28.5
unnamed: D41.C, R82.1
unnamed: C89.2, U29.1, Y8.P$2
unnamed: C90.1, U29.2, Y8.P$1
unnamed: D44.A, R86.1
unnamed: D45.A, R87.1
unnamed: D45.C, Q15.3
unnamed: F8.1, JP65.VBUS1
unnamed: D43.A, R90.1
unnamed: D46.A, R92.1
unnamed: D44.C, SJ15.2
unnamed: R93.2, SJ16.1
unnamed: R95.2, SJ16.2, U32.5
unnamed: D47.C, R94.1
PA1: JP16.5, U5.22
PA2: JP25.5, U9.22
PA3: JP34.5, U13.22
PA4: JP43.5, U17.22
PA5: JP52.5, U21.22
PA6: JP61.5, U25.22
PA7: JP70.5, U29.22
PA13: JP5.5, U4.22
PB1: JP16.4, U5.37
PB2: JP16.3, U5.38
PB3: JP25.4, U9.37
PB4: JP25.3, U9.38
PB5: JP34.4, U13.37
PB6: JP34.3, U13.38
PB7: JP43.4, U17.37
PB8: JP43.3, U17.38
PB9: JP52.4, U21.37
PB10: JP52.3, U21.38
PB11: JP61.4, U25.37
PB12: JP61.3, U25.38
PB13: JP70.4, U29.37
PB14: JP70.3, U29.38
PB22: JP5.4, U4.37
PB23: JP5.3, U4.38
RX_LED: D6.C, U4.48
RX_LED1: D10.C, U5.48
RX_LED2: D16.C, U9.48
RX_LED3: D22.C, U13.48
RX_LED4: D28.C, U17.48
RX_LED5: D34.C, U21.48
RX_LED6: D40.C, U25.48
RX_LED7: D46.C, U29.48
SCL: JP7.SCL, U4.32
SCL1: JP12.SCL, U5.32
SCL2: JP21.SCL, U9.32
SCL3: JP30.SCL, U13.32
SCL4: JP39.SCL, U17.32
SCL5: JP48.SCL, U21.32
SCL6: JP57.SCL, U25.32
SCL7: JP66.SCL, U29.32
SDA: JP7.SDA, U4.31
SDA1: JP12.SDA, U5.31
SDA2: JP21.SDA, U9.31
SDA3: JP30.SDA, U13.31
SDA4: JP39.SDA, U17.31
SDA5: JP48.SDA, U21.31
SDA6: JP57.SDA, U25.31
SDA7: JP66.SDA, U29.31
SPI_MISO: JP7.MISO, U4.21
SPI_MISO1: JP12.MISO, U5.21
SPI_MISO2: JP21.MISO, U9.21
SPI_MISO3: JP30.MISO, U13.21
SPI_MISO4: JP39.MISO, U17.21
SPI_MISO5: JP48.MISO, U21.21
SPI_MISO6: JP57.MISO, U25.21
SPI_MISO7: JP66.MISO, U29.21
SPI_MOSI: JP7.MOSI, U4.19
SPI_MOSI1: JP12.MOSI, U5.19
SPI_MOSI2: JP21.MOSI, U9.19
SPI_MOSI3: JP30.MOSI, U13.19
SPI_MOSI4: JP39.MOSI, U17.19
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

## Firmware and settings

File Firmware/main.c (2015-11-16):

/* ----------------------------------------------------------------------------
 *         SAM Software Package License
 * ----------------------------------------------------------------------------
 * Copyright (c) 2011-2012, Atmel Corporation
 *
 * All rights reserved.
 *
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
 * Atmel's name may not be used to endorse or promote products derived from
 * this software without specific prior written permission.
 *
 * DISCLAIMER: THIS SOFTWARE IS PROVIDED BY ATMEL "AS IS" AND ANY EXPRESS OR
 * IMPLIED WARRANTIES, INCLUDING, BUT NOT LIMITED TO, THE IMPLIED WARRANTIES OF
 * MERCHANTABILITY, FITNESS FOR A PARTICULAR PURPOSE AND NON-INFRINGEMENT ARE
 * DISCLAIMED. IN NO EVENT SHALL ATMEL BE LIABLE FOR ANY DIRECT, INDIRECT,
 * INCIDENTAL, SPECIAL, EXEMPLARY, OR CONSEQUENTIAL DAMAGES (INCLUDING, BUT NOT
 * LIMITED TO, PROCUREMENT OF SUBSTITUTE GOODS OR SERVICES; LOSS OF USE, DATA,
 * OR PROFITS; OR BUSINESS INTERRUPTION) HOWEVER CAUSED AND ON ANY THEORY OF
 * LIABILITY, WHETHER IN CONTRACT, STRICT LIABILITY, OR TORT (INCLUDING
 * NEGLIGENCE OR OTHERWISE) ARISING IN ANY WAY OUT OF THE USE OF THIS SOFTWARE,
 * EVEN IF ADVISED OF THE POSSIBILITY OF SUCH DAMAGE.
 * ----------------------------------------------------------------------------
 */

/**
 * --------------------
 * SAM-BA Implementation on SAMD21
 * --------------------
 * Requirements to use SAM-BA :
 *
 * Supported communication interfaces :
 * --------------------
 *
 * SERCOM5 : RX:PB23 TX:PB22
 * Baudrate : 115200 8N1
 *
 * USB : D-:PA24 D+:PA25
 *
 * Pins Usage
 * --------------------
 * The following pins are used by the program :
 * PA25 : input/output
 * PA24 : input/output
 * PB23 : input
 * PB22 : output
 * PA15 : input
 *
 * The application board shall avoid driving the PA25,PA24,PB23,PB22 and PA15 signals
 * while the boot program is running (after a POR for example)
 *
 * Clock system
 * --------------------
 * CPU clock source (GCLK_GEN_0) - 8MHz internal oscillator (OSC8M)
 * SERCOM5 core GCLK source (GCLK_ID_SERCOM5_CORE) - GCLK_GEN_0 (i.e., OSC8M)
 * GCLK Generator 1 source (GCLK_GEN_1) - 48MHz DFLL in Clock Recovery mode (DFLL48M)
 * USB GCLK source (GCLK_ID_USB) - GCLK_GEN_1 (i.e., DFLL in CRM mode)
 *
 * Memory Mapping
 * --------------------
 * SAM-BA code will be located at 0x0 and executed before any applicative code.
 *
 * Applications compiled to be executed along with the bootloader will start at
 * 0x2000
 * Before jumping to the application, the bootloader changes the VTOR register
 * to use the interrupt vectors of the application @0x2000.<- not required as
 * application code is taking care of this
 *
*/

#include <stdio.h>
#include <sam.h>
#include "compiler.h"
#include "sam_ba_monitor.h"
#include "usart_sam_ba.h"
#include "main.h"
#include "cdc_enumerate.h"

#define NVM_SW_CALIB_DFLL48M_COARSE_VAL   58
#define NVM_SW_CALIB_DFLL48M_FINE_VAL     64

static void check_start_application(void);

static volatile bool main_b_cdc_enable = false;

/**
 * \brief Check the application startup condition
 *
 */
static void check_start_application(void)
{
	volatile PortGroup *led_port = (volatile PortGroup *)&PORT->Group[1];
	led_port->DIRSET.reg = (1<<30);
	led_port->OUTCLR.reg = (1<<30);

#if defined(BOOT_DOUBLE_TAP_ADDRESS)
	#define DOUBLE_TAP_MAGIC 0x07738135
	if (PM->RCAUSE.bit.POR)
	{
		/* On power-on initialize double-tap */
		BOOT_DOUBLE_TAP_DATA = 0;
	}
	else
	{
		if (BOOT_DOUBLE_TAP_DATA == DOUBLE_TAP_MAGIC) {
			/* Second tap, stay in bootloader */
			BOOT_DOUBLE_TAP_DATA = 0;
			return;
		}

		/* First tap */
		BOOT_DOUBLE_TAP_DATA = DOUBLE_TAP_MAGIC;

		/* Wait 0.5sec to see if the user tap reset again */
		for (uint32_t i=0; i<125000; i++) /* 500ms */
			/* force compiler to not optimize this... */
			__asm__ __volatile__("");

		/* Timeout happened, continue boot... */
		BOOT_DOUBLE_TAP_DATA = 0;
	}
#endif

	uint32_t app_start_address;

	/* Load the Reset Handler address of the application */
	app_start_address = *(uint32_t *)(APP_START_ADDRESS + 4);

	/**
	 * Test reset vector of application @APP_START_ADDRESS+4
	 * Stay in SAM-BA if *(APP_START+0x4) == 0xFFFFFFFF
	 * Application erased condition
	 */
	if (app_start_address == 0xFFFFFFFF) {
		/* Stay in bootloader */
		return;
	}

#if defined(BOOT_LOAD_PIN)
	volatile PortGroup *boot_port = (volatile PortGroup *)(&(PORT->Group[BOOT_LOAD_PIN / 32]));
	volatile bool boot_en;

	/* Enable the input mode in Boot GPIO Pin */
	boot_port->DIRCLR.reg = BOOT_PIN_MASK;
	boot_port->PINCFG[BOOT_LOAD_PIN & 0x1F].reg = PORT_PINCFG_INEN | PORT_PINCFG_PULLEN;
	boot_port->OUTSET.reg = BOOT_PIN_MASK;
	/* Read the BOOT_LOAD_PIN status */
	boot_en = (boot_port->IN.reg) & BOOT_PIN_MASK;

	/* Check the bootloader enable condition */
	if (!boot_en) {
		/* Stay in bootloader */
		return;
	}
#endif

	led_port->OUTSET.reg = (1<<30);

	/* Rebase the Stack Pointer */
	__set_MSP(*(uint32_t *) APP_START_ADDRESS);

	/* Rebase the vector table base address */
	SCB->VTOR = ((uint32_t) APP_START_ADDRESS & SCB_VTOR_TBLOFF_Msk);

	/* Jump to application Reset Handler in the application */
	asm("bx %0"::"r"(app_start_address));
}

void system_init()
{
	PORT->Group[1].DIRSET.reg = (1<<3);
	PORT->Group[1].OUTSET.reg = (1<<3);
	PORT->Group[0].DIRSET.reg = (1<<27);
	PORT->Group[0].OUTSET.reg = (1<<27);
	/* Configure flash wait states */
	NVMCTRL->CTRLB.bit.RWS = FLASH_WAIT_STATES;

	/* Set OSC8M prescalar to divide by 1 */
	SYSCTRL->OSC8M.bit.PRESC = 0;

	/* Configure OSC8M as source for GCLK_GEN0 */
	GCLK_GENCTRL_Type genctrl={0};
	uint32_t temp_genctrl;
	GCLK->GENCTRL.bit.ID = 0; /* GENERATOR_ID - GCLK_GEN_0 */
	while(GCLK->STATUS.reg & GCLK_STATUS_SYNCBUSY);
	temp_genctrl = GCLK->GENCTRL.reg;
	genctrl.bit.SRC = GCLK_GENCTRL_SRC_OSC8M_Val;
	genctrl.bit.GENEN = true;
	genctrl.bit.RUNSTDBY = false;
	GCLK->GENCTRL.reg = (genctrl.reg | temp_genctrl);
	while(GCLK->STATUS.reg & GCLK_STATUS_SYNCBUSY);

#if SAM_BA_INTERFACE == SAM_BA_USBCDC_ONLY  ||  SAM_BA_INTERFACE == SAM_BA_BOTH_INTERFACES
	SYSCTRL_DFLLCTRL_Type dfllctrl_conf = {0};
	SYSCTRL_DFLLVAL_Type dfllval_conf = {0};
	uint32_t coarse =( *((uint32_t *)(NVMCTRL_OTP4)
                    + (NVM_SW_CALIB_DFLL48M_COARSE_VAL / 32))
                    >> (NVM_SW_CALIB_DFLL48M_COARSE_VAL % 32))
                    & ((1 << 6) - 1);
	if (coarse == 0x3f) {
		coarse = 0x1f;
	}
	uint32_t fine =( *((uint32_t *)(NVMCTRL_OTP4)
                  + (NVM_SW_CALIB_DFLL48M_FINE_VAL / 32))
                  >> (NVM_SW_CALIB_DFLL48M_FINE_VAL % 32))
                  & ((1 << 10) - 1);
	if (fine == 0x3ff) {
		fine = 0x1ff;
	}
	dfllval_conf.bit.COARSE  = coarse;
	dfllval_conf.bit.FINE    = fine;
	dfllctrl_conf.bit.USBCRM = true;
	dfllctrl_conf.bit.BPLCKC = false;
	dfllctrl_conf.bit.QLDIS  = false;
	dfllctrl_conf.bit.CCDIS  = true;
	dfllctrl_conf.bit.ENABLE = true;

	SYSCTRL->DFLLCTRL.bit.ONDEMAND = false;
	while (!(SYSCTRL->PCLKSR.reg & SYSCTRL_PCLKSR_DFLLRDY));
	SYSCTRL->DFLLMUL.reg = 48000;
	SYSCTRL->DFLLVAL.reg = dfllval_conf.reg;
	SYSCTRL->DFLLCTRL.reg = dfllctrl_conf.reg;

	GCLK_CLKCTRL_Type clkctrl={0};
	uint16_t temp;
	GCLK->CLKCTRL.bit.ID = 0; /* GCLK_ID - DFLL48M Reference */
	temp = GCLK->CLKCTRL.reg;
	clkctrl.bit.CLKEN = true;
	clkctrl.bit.WRTLOCK = false;
	clkctrl.bit.GEN = GCLK_CLKCTRL_GEN_GCLK0_Val;
	GCLK->CLKCTRL.reg = (clkctrl.reg | temp);

	/* Configure DFLL48M as source for GCLK_GEN1 */
	GCLK->GENCTRL.bit.ID = 1; /* GENERATOR_ID - GCLK_GEN_1 */
	while(GCLK->STATUS.reg & GCLK_STATUS_SYNCBUSY);
	temp_genctrl = GCLK->GENCTRL.reg;
	genctrl.bit.SRC = GCLK_GENCTRL_SRC_DFLL48M_Val;
	genctrl.bit.GENEN = true;
	genctrl.bit.RUNSTDBY = false;
	GCLK->GENCTRL.reg = (genctrl.reg | temp_genctrl);
	while(GCLK->STATUS.reg & GCLK_STATUS_SYNCBUSY);
#endif
}


#if DEBUG_ENABLE
#	define DEBUG_PIN_HIGH 	port_pin_set_output_level(BOOT_LED, 1)
#	define DEBUG_PIN_LOW 	port_pin_set_output_level(BOOT_LED, 0)
#else
#	define DEBUG_PIN_HIGH 	do{}while(0)
#	define DEBUG_PIN_LOW 	do{}while(0)
#endif


/**
 *  \brief SAMD21 SAM-BA Main loop.
 *  \return Unused (ANSI-C compatibility).
 */
int main(void)
{
#if SAM_BA_INTERFACE == SAM_BA_USBCDC_ONLY  ||  SAM_BA_INTERFACE == SAM_BA_BOTH_INTERFACES 
	P_USB_CDC pCdc;
#endif
	DEBUG_PIN_HIGH;

	/* Jump in application if condition is satisfied */
	check_start_application();

	/* We have determined we should stay in the monitor. */
	/* System initialization */
	system_init();
	cpu_irq_enable();

	#if SAM_BA_INTERFACE == SAM_BA_UART_ONLY  ||  SAM_BA_INTERFACE == SAM_BA_BOTH_INTERFACES
	/* UART is enabled in all cases */
	usart_open();
#endif

#if SAM_BA_INTERFACE == SAM_BA_USBCDC_ONLY  ||  SAM_BA_INTERFACE == SAM_BA_BOTH_INTERFACES
	pCdc = (P_USB_CDC)usb_init();
#endif
	DEBUG_PIN_LOW;
	/* Wait for a complete enum on usb or a '#' char on serial line */
	while (1) {
#if SAM_BA_INTERFACE == SAM_BA_USBCDC_ONLY  ||  SAM_BA_INTERFACE == SAM_BA_BOTH_INTERFACES
		if (pCdc->IsConfigured(pCdc) != 0) {
			main_b_cdc_enable = true;
		}

		//Check if a USB enumeration has succeeded
		//And com port was opened
		if (main_b_cdc_enable) {
			sam_ba_monitor_init(SAM_BA_INTERFACE_USBCDC);
			//SAM-BA on USB loop
			while(1) {
				sam_ba_monitor_run();
			}
		}
#endif
#if SAM_BA_INTERFACE == SAM_BA_UART_ONLY  ||  SAM_BA_INTERFACE == SAM_BA_BOTH_INTERFACES
		/* Check if a '#' has been received */
		if (!main_b_cdc_enable && usart_sharp_received()) {
			sam_ba_monitor_init(SAM_BA_INTERFACE_USART);
			/* SAM-BA on UART loop */
			while(1) {
				sam_ba_monitor_run();
			}
		}
#endif
	}
}

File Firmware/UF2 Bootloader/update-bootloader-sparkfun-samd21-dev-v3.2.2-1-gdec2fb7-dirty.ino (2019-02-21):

// Bootloader update sketch. Paste into Arduino IDE and upload to the device
// to update bootloader. It will blink a few times and then start pulsing.
// Your OS will then detect a USB mass storage device.
#include <stdint.h>
const uint8_t bootloader[8192] __attribute__ ((aligned (4))) = {0xd8, 0x2d, 0x00, 0x20, 0x81, 0x02, 0x00, 0x00, 0x7d, 0x02, 0x00, 0x00, 0x7f, 0x02, 0x00, 0x00,
0x00, 0x00, 0x00, 0x00, 0x00, 0x00, 0x00, 0x00, 0x00, 0x00, 0x00, 0x00, 0x00, 0x00, 0x00, 0x00,
0x00, 0x00, 0x00, 0x00, 0x00, 0x00, 0x00, 0x00, 0x00, 0x00, 0x00, 0x00, 0x7d, 0x02, 0x00, 0x00,
0x00, 0x00, 0x00, 0x00, 0x00, 0x00, 0x00, 0x00, 0x7d, 0x02, 0x00, 0x00, 0x75, 0x02, 0x00, 0x00,
0x7d, 0x02, 0x00, 0x00, 0x7d, 0x02, 0x00, 0x00, 0x7d, 0x02, 0x00, 0x00, 0x7d, 0x02, 0x00, 0x00,
0x7d, 0x02, 0x00, 0x00, 0x7d, 0x02, 0x00, 0x00, 0x7d, 0x02, 0x00, 0x00, 0x7d, 0x02, 0x00, 0x00,
0x7d, 0x02, 0x00, 0x00, 0x7d, 0x02, 0x00, 0x00, 0x7d, 0x02, 0x00, 0x00, 0x7d, 0x02, 0x00, 0x00,
0x7d, 0x02, 0x00, 0x00, 0x7d, 0x02, 0x00, 0x00, 0x7d, 0x02, 0x00, 0x00, 0x7d, 0x02, 0x00, 0x00,
0x7d, 0x02, 0x00, 0x00, 0x7d, 0x02, 0x00, 0x00, 0x7d, 0x02, 0x00, 0x00, 0x7d, 0x02, 0x00, 0x00,
0x7d, 0x02, 0x00, 0x00, 0x00, 0x00, 0x00, 0x00, 0x00, 0x00, 0x00, 0x00, 0x7d, 0x02, 0x00, 0x00,
0x7d, 0x02, 0x00, 0x00, 0x7d, 0x02, 0x00, 0x00, 0x7d, 0x02, 0x00, 0x00, 0x7d, 0x02, 0x00, 0x00,
0x00, 0x00, 0x00, 0x00, 0x07, 0x4b, 0x1a, 0x7d, 0xd2, 0x07, 0xfb, 0xd5, 0x20, 0x22, 0xff, 0x32,
0x1a, 0x83, 0x05, 0x4a, 0x40, 0x08, 0xd8, 0x61, 0x1a, 0x80, 0x1a, 0x7d, 0xd2, 0x07, 0xfc, 0xd5,
0x70, 0x47, 0xc0, 0x46, 0x00, 0x40, 0x00, 0x41, 0x02, 0xa5, 0xff, 0xff, 0x10, 0xb5, 0x04, 0x1c,
0x04, 0x4b, 0x9c, 0x42, 0x05, 0xd8, 0x20, 0x1c, 0x01, 0x34, 0xff, 0xf7, 0xe3, 0xff, 0xff, 0x34,
0xf6, 0xe7, 0x10, 0xbd, 0xff, 0xff, 0x03, 0x00, 0x00, 0x23, 0x30, 0xb5, 0x93, 0x42, 0x04, 0xd0,
0x9c, 0x00, 0x0d, 0x59, 0x01, 0x33, 0x05, 0x51, 0xf8, 0xe7, 0x30, 0xbd, 0x70, 0xb5, 0x80, 0x25,
0x0f, 0x4b, 0x5c, 0x68, 0xac, 0x43, 0x5c, 0x60, 0x00, 0x2a, 0x18, 0xd0, 0x14, 0x1e, 0x10, 0x2c,
0x00, 0xd9, 0x10, 0x24, 0x0b, 0x4d, 0x12, 0x1b, 0x1d, 0x80, 0x1d, 0x7d, 0xed, 0x07, 0xfc, 0xd5,
0xa5, 0x00, 0x00, 0x24, 0x0e, 0x59, 0x06, 0x51, 0x04, 0x34, 0xac, 0x42, 0xfa, 0xd1, 0x00, 0x19,
0x09, 0x19, 0x05, 0x4c, 0x1c, 0x80, 0x1c, 0x7d, 0xe4, 0x07, 0xfc, 0xd5, 0xe4, 0xe7, 0x70, 0xbd,
0x00, 0x40, 0x00, 0x41, 0x44, 0xa5, 0xff, 0xff, 0x04, 0xa5, 0xff, 0xff, 0x38, 0xb5, 0x00, 0x23,
0xca, 0x58, 0xc4, 0x58, 0xa2, 0x42, 0x05, 0xd1, 0x80, 0x22, 0x04, 0x33, 0x52, 0x00, 0x93, 0x42,
0xf6, 0xd1, 0x08, 0xe0, 0x0d, 0x1c, 0x04, 0x1c, 0xff, 0xf7, 0x9c, 0xff, 0x20, 0x1c, 0x29, 0x1c,
0x40, 0x22, 0xff, 0xf7, 0xc3, 0xff, 0x38, 0xbd, 0x02, 0x4b, 0x5b, 0x78, 0x5b, 0xb2, 0x00, 0x2b,
0xfa, 0xdb, 0x70, 0x47, 0x00, 0x0c, 0x00, 0x40, 0x02, 0x4b, 0xdb, 0x68, 0xdb, 0x06, 0xfb, 0xd5,
0x70, 0x47, 0xc0, 0x46, 0x00, 0x08, 0x00, 0x40, 0x1e, 0x21, 0xf8, 0xb5, 0x02, 0x26, 0x25, 0x4a,
0x25, 0x4c, 0x53, 0x68, 0x25, 0x4d, 0x8b, 0x43, 0x33, 0x43, 0x53, 0x60, 0xa6, 0x60, 0xff, 0xf7,
0xe3, 0xff, 0x23, 0x4b, 0x63, 0x60, 0xff, 0xf7, 0xdf, 0xff, 0xae, 0x84, 0xff, 0xf7, 0xe4, 0xff,
0x20, 0x4b, 0x1b, 0x68, 0x9b, 0x0e, 0x3f, 0x2b, 0x00, 0xd1, 0x20, 0x3b, 0x00, 0x26, 0x02, 0x27,
0x1d, 0x4a, 0x9b, 0x02, 0x13, 0x43, 0x1d, 0x4a, 0xea, 0x62, 0xab, 0x62, 0xae, 0x84, 0xff, 0xf7,
0xd3, 0xff, 0x1b, 0x4b, 0xab, 0x84, 0xff, 0xf7, 0xcf, 0xff, 0xab, 0x8c, 0x3b, 0x43, 0xab, 0x84,
0xff, 0xf7, 0xca, 0xff, 0x3f, 0x22, 0x63, 0x88, 0x93, 0x43, 0x3b, 0x43, 0x63, 0x80, 0x80, 0x23,
0x62, 0x88, 0xdb, 0x01, 0x13, 0x43, 0x63, 0x80, 0xa6, 0x60, 0xff, 0xf7, 0xb5, 0xff, 0x11, 0x4b,
0x63, 0x60, 0xff, 0xf7, 0xb1, 0xff, 0xc0, 0x20, 0x0f, 0x4a, 0x10, 0x4b, 0x10, 0x49, 0x53, 0x60,
0x0b, 0x6a, 0x00, 0x06, 0x1b, 0x02, 0x1b, 0x0a, 0x03, 0x43, 0x0b, 0x62, 0x07, 0x23, 0x96, 0x60,
0x13, 0x60, 0xf8, 0xbd, 0x00, 0x40, 0x00, 0x41, 0x00, 0x0c, 0x00, 0x40, 0x00, 0x08, 0x00, 0x40,
0x06, 0x00, 0x01, 0x00, 0x24, 0x60, 0x80, 0x00, 0xff, 0x01, 0x00, 0x00, 0x80, 0xbb, 0x0a, 0x1c,
0x24, 0x05, 0x00, 0x00, 0x00, 0x07, 0x03, 0x00, 0x10, 0xe0, 0x00, 0xe0, 0xe7, 0x03, 0x00, 0x00,
0x00, 0xed, 0x00, 0xe0, 0x08, 0xb5, 0x00, 0xf0, 0xf3, 0xf8, 0x08, 0xbd, 0xfe, 0xe7, 0xfe, 0xe7,
0x20, 0x48, 0x21, 0x49, 0x70, 0xb5, 0x00, 0x23, 0x88, 0x42, 0x01, 0xd1, 0x1f, 0x4b, 0x07, 0xe0,
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

};
const uint16_t bootloader_crcs[] = {0x3781 ,0x7d55 ,0x7224 ,0x87cd ,0x8db2 ,0xbdc4 ,0xe700 ,0xfb0b};
#define BOOTLOADER_K 8

static uint16_t crcCache[256];

#define CRC16POLY 0x1021

#define FLASH_ROW_SIZE (FLASH_PAGE_SIZE * 4)

uint16_t add_crc(uint8_t ch, unsigned short crc0) {
    if (!crcCache[1]) {
        for (int ptr = 0; ptr < 256; ptr++) {
            uint16_t crc = (int)ptr << 8;
            for (uint16_t cmpt = 0; cmpt < 8; cmpt++) {
                if (crc & 0x8000)
                    crc = crc << 1 ^ CRC16POLY;
                else
                    crc = crc << 1;
            }
            crcCache[ptr] = crc;
        }
    }

    return ((crc0 << 8) ^ crcCache[((crc0 >> 8) ^ ch) & 0xff]) & 0xffff;
}

uint8_t pageBuf[FLASH_ROW_SIZE];

#define NVM_USER_MEMORY ((volatile uint16_t *)NVMCTRL_USER)

static inline void wait_ready(void) {
    while (NVMCTRL->INTFLAG.bit.READY == 0) {
    }
}

void flash_erase_row(uint32_t *dst) {
    wait_ready();
    NVMCTRL->STATUS.reg = NVMCTRL_STATUS_MASK;

    // Execute "ER" Erase Row
    NVMCTRL->ADDR.reg = (uint32_t)dst / 2;
    NVMCTRL->CTRLA.reg = NVMCTRL_CTRLA_CMDEX_KEY | NVMCTRL_CTRLA_CMD_ER;
    wait_ready();
}

void flash_write_words(uint32_t *dst, uint32_t *src, uint32_t n_words) {
    // Set automatic page write
    NVMCTRL->CTRLB.bit.MANW = 0;

    while (n_words > 0) {
        uint32_t len = min(FLASH_PAGE_SIZE >> 2, n_words);
        n_words -= len;

        // Execute "PBC" Page Buffer Clear
        NVMCTRL->CTRLA.reg = NVMCTRL_CTRLA_CMDEX_KEY | NVMCTRL_CTRLA_CMD_PBC;
        wait_ready();

        // make sure there are no other memory writes here
        // otherwise we get lock-ups

        while (len--)
            *dst++ = *src++;

        // Execute "WP" Write Page
        NVMCTRL->CTRLA.reg = NVMCTRL_CTRLA_CMDEX_KEY | NVMCTRL_CTRLA_CMD_WP;
        wait_ready();
    }
}

void flash_write_row(uint32_t *dst, uint32_t *src) {
    flash_erase_row(dst);
    flash_write_words(dst, src, FLASH_ROW_SIZE / 4);
}

#define exec_cmd(cmd)                                                                              \
    do {                                                                                           \
        NVMCTRL->STATUS.reg |= NVMCTRL_STATUS_MASK;                                                \
        NVMCTRL->ADDR.reg = (uint32_t)NVMCTRL_USER / 2;                                            \
        NVMCTRL->CTRLA.reg = NVMCTRL_CTRLA_CMDEX_KEY | cmd;                                        \
        while (NVMCTRL->INTFLAG.bit.READY == 0)                                                    \
            ;                                                                                      \
    } while (0)
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

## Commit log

2015-06-09 Initial commit of PCB layout.
    [sparkfun-samd21g18-r3.brd, sparkfun-samd21g18-r3.sch]
2015-06-09 Minor fixes for pre-QC check.
    [sparkfun-samd21g18-r3.brd, sparkfun-samd21g18-r3.sch]
2015-06-10 Adding SMD JST package, moving LEDs and USB to accomodate.
    [sparkfun-samd21g18-r3.brd, sparkfun-samd21g18-r3.sch]
2015-06-10 Renaming files and board name silk.
    [sparkfun-samd21g-r3.brd, sparkfun-samd21g-r3.sch]
2015-06-10 Re-routing some traces to increase ground pour.
    [sparkfun-samd21g-r3.brd]
2015-06-15 Adding PROD_ID to L1.
    [sparkfun-samd21g-r3.brd, sparkfun-samd21g-r3.sch]
2015-09-28 Swapping D2 and D4.
    [sparkfun-samd21g-r3.brd, sparkfun-samd21g-r3.sch]
2015-09-28 Moving Cortex-M0 programming header down 0.025"
    [sparkfun-samd21g-r3.brd]
2015-09-28 Adding pull-down resistor to D13 LED/MOSFET
    [sparkfun-samd21g-r3.brd, sparkfun-samd21g-r3.sch]
2015-09-28 Upping version number to v10
    [sparkfun-samd21g-r3.brd, sparkfun-samd21g-r3.sch]
2015-09-28 Pulling buffer up to VIN instead of 3.3V
    [sparkfun-samd21g-r3.brd, sparkfun-samd21g-r3.sch]
2015-09-28 Swapping MIC5205 Regulator out for AP2112K-3.3V
    [sparkfun-samd21g-r3.brd, sparkfun-samd21g-r3.sch]
2015-09-28 Adding pin numbers to middle-board pins. Adding PWM indicators.
    [sparkfun-samd21g-r3.brd, sparkfun-samd21g-r3.sch]
2015-09-29 Tweaking schematic and layout silk for checklist
    [sparkfun-samd21g-r3.brd, sparkfun-samd21g-r3.sch]
2015-09-30 Adding silk to detail serial ports and DAC pin
    [sparkfun-samd21g-r3.brd]
2015-09-30 One last little silk clean up
    [sparkfun-samd21g-r3.brd]
2015-10-07 created panel v10
    [sparkfun-samd21g-r3-panel-v10.brd]
2015-10-29 Fixing typo in comment about SJ1.
    [sparkfun-samd21g-r3.sch]
2015-11-12 Revising file name to match product name.
    [sparkfun-samd21-pro-breakout.brd, sparkfun-samd21-pro-breakout.sch]
2015-11-12 Adding version 1.0 of the schematic.
2019-02-21 Adds UF2 binary and arduino sketch update bootloader as well as just the bootloader.
    * Adds readme explaining UF2 bootloaders and Circuit Python
    * Adds Circuit Python UF2 file

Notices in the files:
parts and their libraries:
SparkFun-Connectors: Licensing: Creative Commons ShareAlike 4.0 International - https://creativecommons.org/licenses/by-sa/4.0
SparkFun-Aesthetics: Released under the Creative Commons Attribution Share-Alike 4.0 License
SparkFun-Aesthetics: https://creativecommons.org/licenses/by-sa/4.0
